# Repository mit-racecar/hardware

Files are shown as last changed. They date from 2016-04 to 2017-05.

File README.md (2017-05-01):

Racecar Hardware
================

This repo has information for recreating the [racecar platform][racecarHomepage]. However, since the racecar platform is still in development, the information in this repo may not always be up to date.

## Bill of Materials (for each car)

### Off the shelf parts
* [Jetson TX1 Developer Kit](http://www.nvidia.com/object/jetson-tx1-dev-kit.html)
* [ZED Stereo Camera](https://www.stereolabs.com/)
* [Hokuyo UST-10LX 2D Lidar](https://acroname.com/products/HOKUYO-UST-10LX-LASER?sku=R359-UST-10LX) 
* [AC1750 Wifi Dual Band Gigabit Router](https://www.amazon.com/TP-Link-Archer-C7-Wireless-Gigabit/dp/B00BUSDVBQ)
* [Ethernet Jumper Cable (1 per car)](https://www.amazon.com/gp/product/B00EEK1114/ref=od_aui_detailpages00?ie=UTF8&psc=1)
* [Traxxas RC Car](https://www.amazon.com/Traxxas-Slash-Brushless-Course-Platinum/dp/B00A0KQH84)
* [7 Port USB 3.0 Hub](https://www.amazon.com/AmazonBasics-Port-USB-Power-Adapter/dp/B00E6GX4BG)
* [Vedder VESC-X HW 4.12 ESC](http://www.enertionboards.com/electric-skateboard-parts/vesc-x-programmable-brushless-motor-controller/)

### Lasercut Parts (from this repo)

* Bottom hardware mounting plate
* Top hardware mounting plate
* Lidar mounting plate
* Extended front bumper

## Notes

### Networking

* The AC1750 Wifi Dual Band Gigabit Routers have a bug in their firmware where "hardware NAT" mode must be disabled for maximum throughput.

[racecarHomepage]: http://racecar.mit.edu/

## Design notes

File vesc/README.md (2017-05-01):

# VESC Configurations

For older VESC versions (i.e. everything except for VESC-X), the 6.141 team recommends using the `6.141_bldc_old_hw_30k_erpm.xml` VESC config.

For the VESC-X, the 6.141 team recommends the `6.141_bldc_VESC_X_hw_30k_erpm.xml` VESC config.

The `traxxas_*` VESC config files are older VESC config versions that were used in previous versions of 6.141.

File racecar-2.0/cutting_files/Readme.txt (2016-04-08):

This set of DXF files contains:

00_RACECAR 12x24 Cutting File.DXF   - Cuts two copies of B1 and B2.

01_RACECAR 12x24 Cutting File.DXF
	thru
06_RACECAR 12x24 Cutting File.DXF   - All of these cut 3 copies of B3.
				      Each one has a different set of
                                      3 car numbers.

All files were made to work with 12x24 sheets of ABS. Note that it is
recommended to construct part B2 out of aluminum instead of ABS to
assist with cooling the laser scanner.

-Owen Guldner

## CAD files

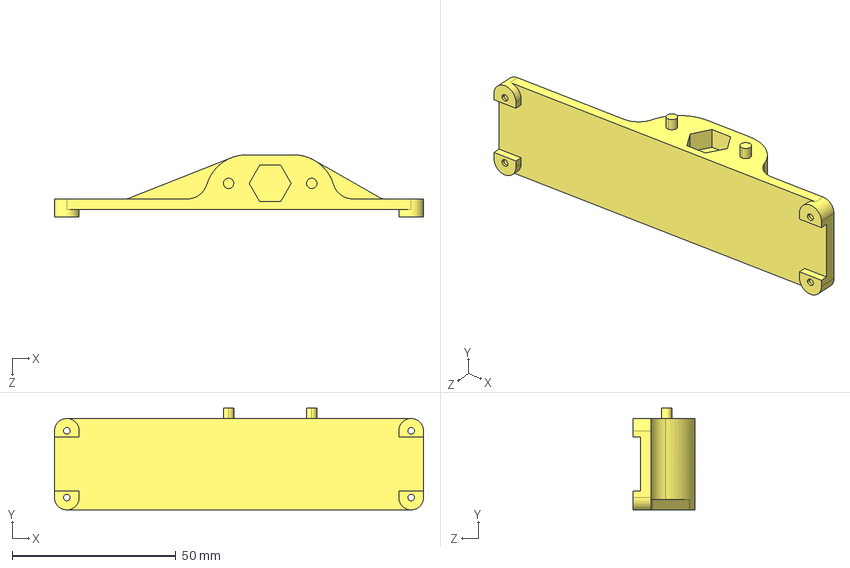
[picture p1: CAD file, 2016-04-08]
racecar-2.0/B5_RevA.STEP
112.7 x 31.1 x 19.1 mm

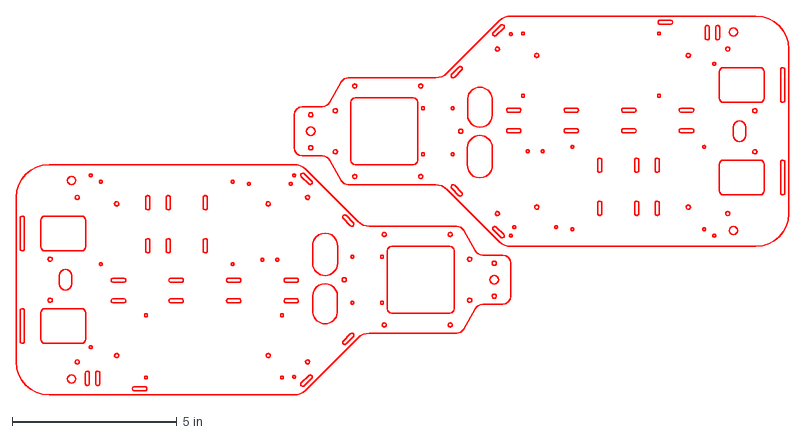
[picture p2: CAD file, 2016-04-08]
racecar-2.0/cutting_files/00_RACECAR 12x24 Cutting File.DXF
23.5 x 11.5 in

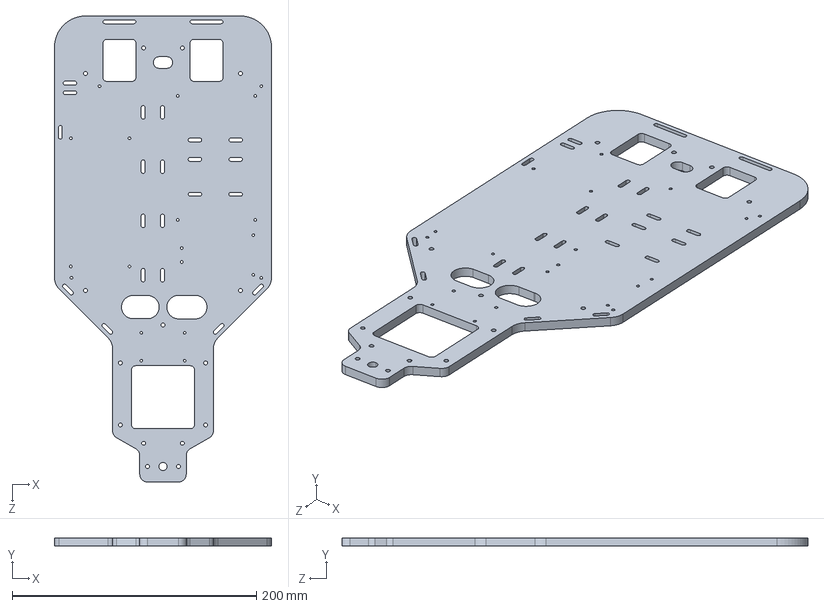
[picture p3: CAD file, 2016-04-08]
racecar-2.0/B1_RevA.STEP
177.8 x 6.35 x 381.8 mm

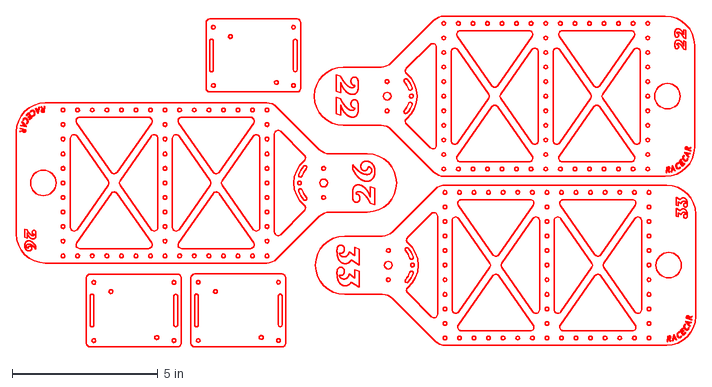
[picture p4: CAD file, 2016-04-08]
racecar-2.0/cutting_files/02_RACECAR 12x24 Cutting File.DXF
23.3 x 11.4 in

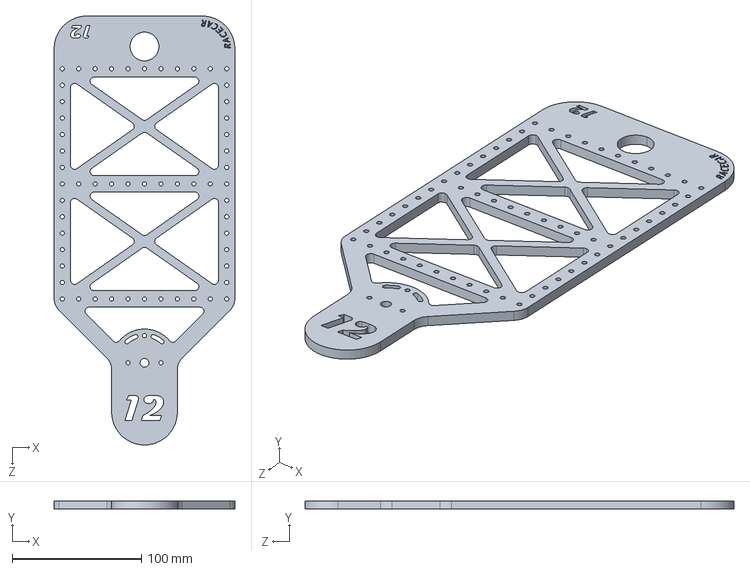
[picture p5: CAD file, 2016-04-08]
racecar-2.0/B3_RevA.STEP
139.7 x 6.35 x 331.4 mm

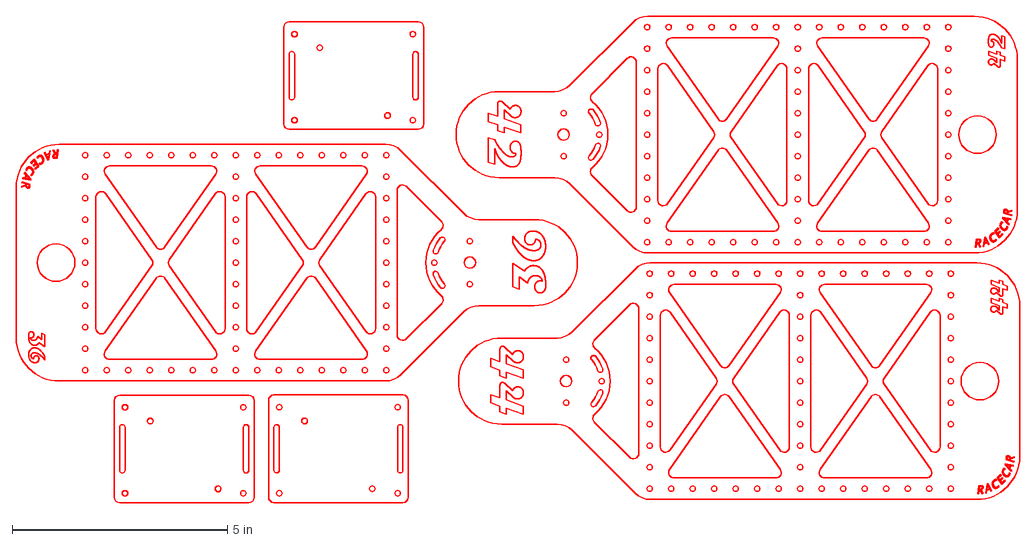
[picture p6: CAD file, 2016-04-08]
racecar-2.0/cutting_files/06_RACECAR 12x24 Cutting File.DXF
23.3 x 11.3 in

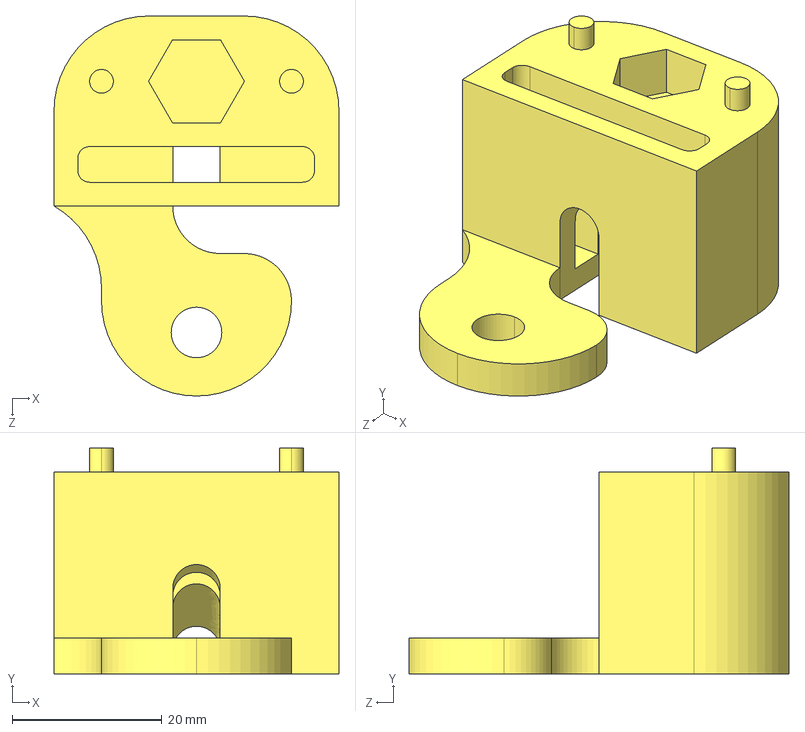
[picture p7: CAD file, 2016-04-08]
racecar-2.0/B4_RevA.STEP
38.1 x 30.2 x 50.8 mm

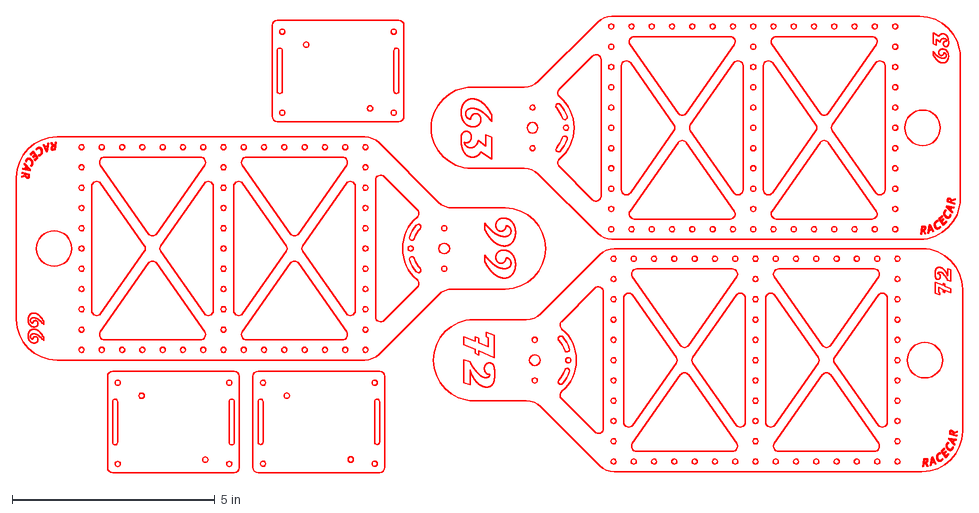
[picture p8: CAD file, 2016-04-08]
racecar-2.0/cutting_files/04_RACECAR 12x24 Cutting File.DXF
23.3 x 11.3 in

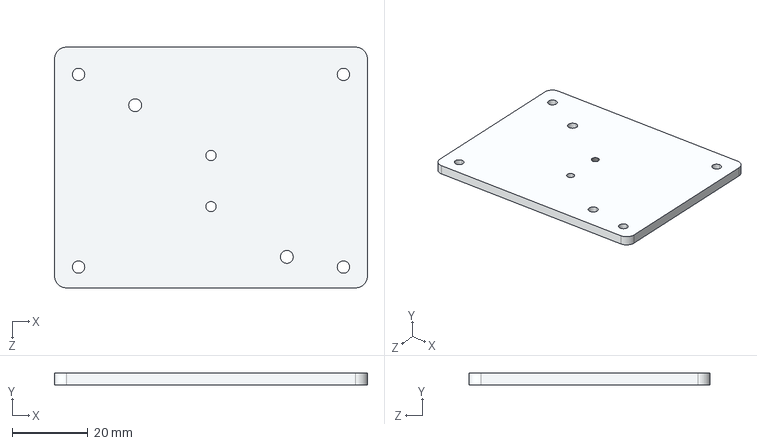
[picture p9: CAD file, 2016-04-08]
racecar-2.0/B2_RevA.STEP
82.5 x 3.18 x 63.5 mm

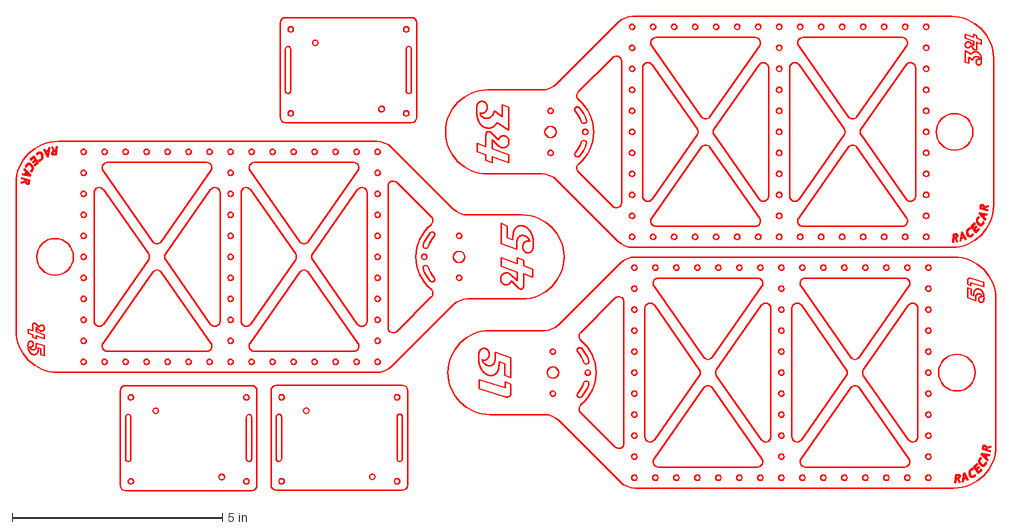
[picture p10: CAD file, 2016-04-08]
racecar-2.0/cutting_files/03_RACECAR 12x24 Cutting File.DXF
23.3 x 11.3 in

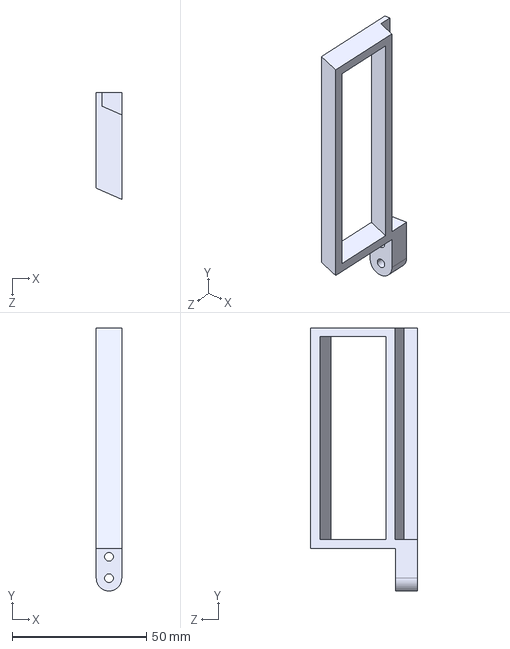
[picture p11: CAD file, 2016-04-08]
racecar-2.0/B6_RevA.STEP
9.53 x 98.0 x 39.8 mm

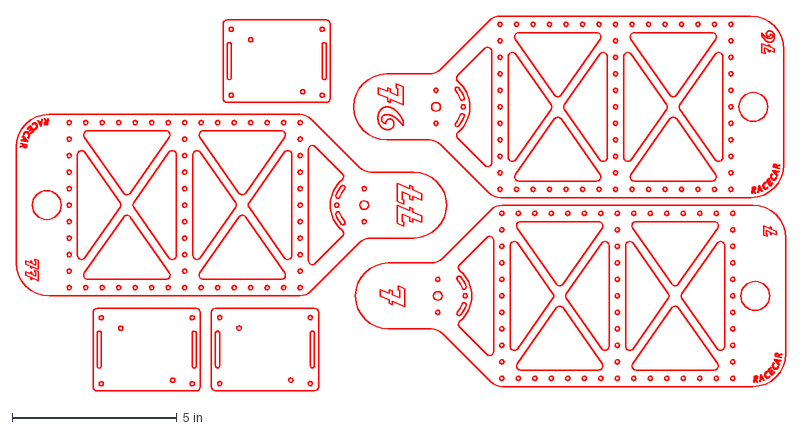
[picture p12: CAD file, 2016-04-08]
racecar-2.0/cutting_files/05_RACECAR 12x24 Cutting File.DXF
23.3 x 11.4 in

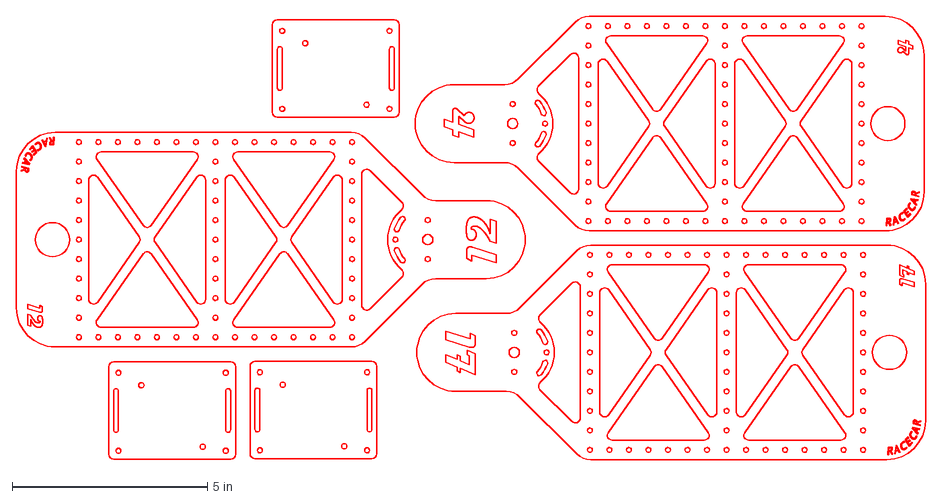
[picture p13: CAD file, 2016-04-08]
racecar-2.0/cutting_files/01_RACECAR 12x24 Cutting File.DXF
23.3 x 11.4 in

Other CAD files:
racecar-2.0/B4_RevA.STL
racecar-2.0/B5_RevA.STL
racecar-2.0/B6_RevA.STL

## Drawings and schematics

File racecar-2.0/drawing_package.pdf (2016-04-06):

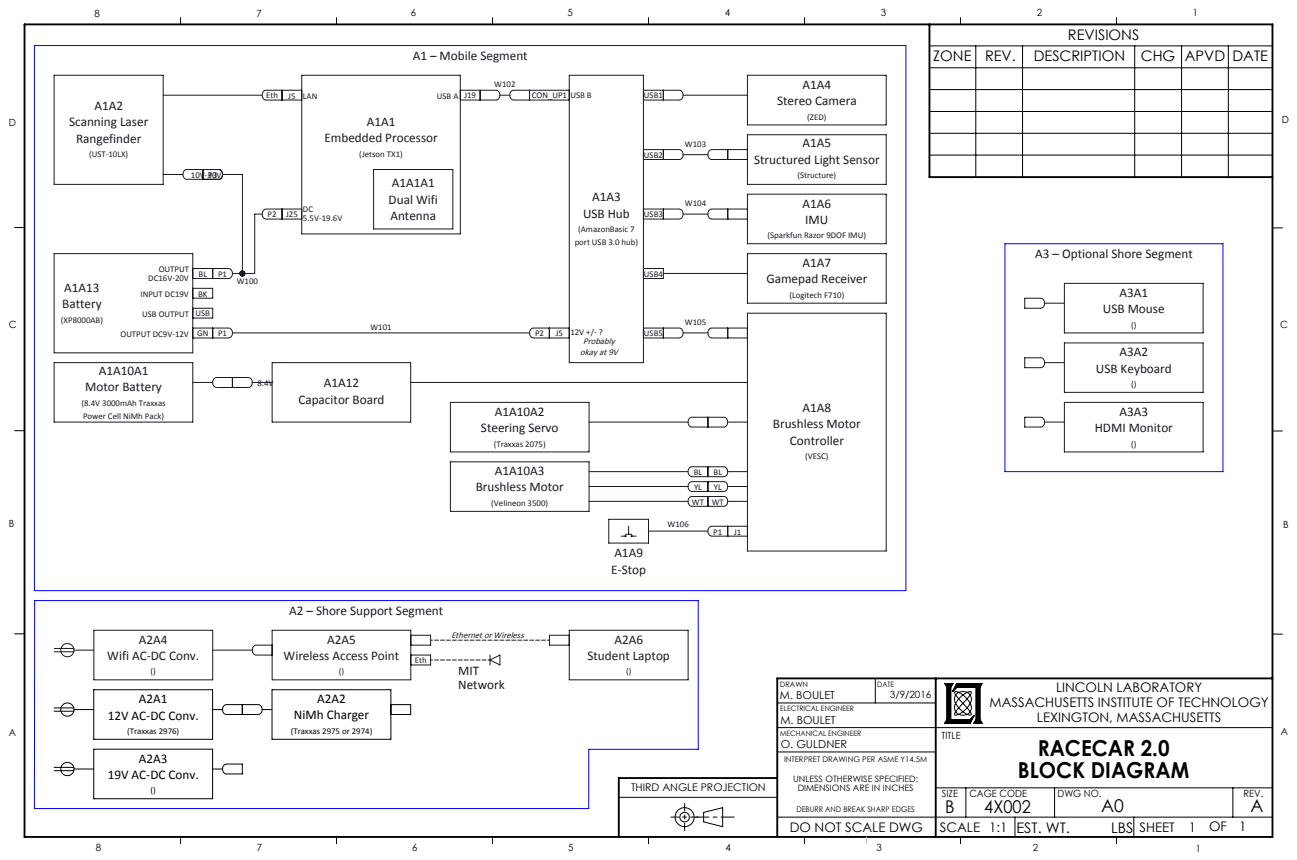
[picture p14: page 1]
Ethernet or Wireless; Student Laptop; NiMh Charger; (Traxxas 2975 or 2974); A1 – Mobile Segment; Embedded Processor; (Jetson TX1); Structured Light Sensor; Scanning Laser; Brushless Motor; Stereo Camera; INPUT DC19V; USB OUTPUT; OUTPUT DC9V-12V; USB A; CON_UP1 USB B; USB1; okay at 9V; Steering Servo; (Traxxas 2075); (Velineon 3500); USB Mouse; USB Keyboard; HDMI Monitor; Capacitor Board; Dual Wifi; RACECAR 2.0 BLOCK DIAGRAM; LINCOLN LABORATORY; LEXINGTON, MASSACHUSETTS

REVISIONS

ZONE | REV. | DESCRIPTION | CHG | APVD | DATE

USB Hub
(AmazonBasic 7
port USB 3.0 hub)

(Sparkfun Razor 9DOF IMU)
Gamepad Receiver
(Logitech F710)

A3 – Optional Shore Segment

Motor Battery
(8.4V 3000mAh Traxxas
Power Cell NiMh Pack)

A2 – Shore Support Segment
Wireless Access Point

Wifi AC-DC Conv.
12V AC-DC Conv.
(Traxxas 2976)
19V AC-DC Conv.

M. BOULET
ELECTRICAL ENGINEER
MECHANICAL ENGINEER
O. GULDNER
INTERPRET DRAWING PER ASME Y14.5M
UNLESS OTHERWISE SPECIFIED:
DIMENSIONS ARE IN INCHES

MASSACHUSETTS INSTITUTE OF TECHNOLOGY

THIRD ANGLE PROJECTION

SIZE B | CAGE CODE 4X002 | DWG NO. A0 | REV. A

DEBURR AND BREAK SHARP EDGES

DO NOT SCALE DWG | SCALE 1:1 | EST. WT. LBS | SHEET 1 OF 1

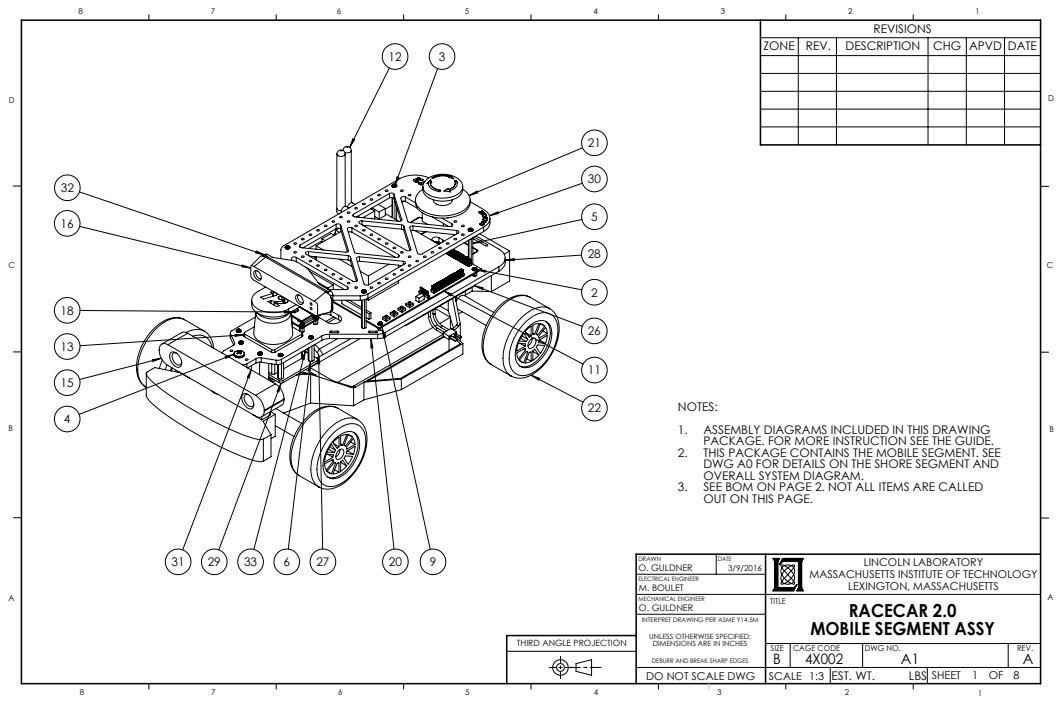
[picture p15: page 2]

NOTES:
1. ASSEMBLY DIAGRAMS INCLUDED IN THIS DRAWING
PACKAGE. FOR MORE INSTRUCTION SEE THE GUIDE.
2. THIS PACKAGE CONTAINS THE MOBILE SEGMENT. SEE
DWG A0 FOR DETAILS ON THE SHORE SEGMENT AND
OVERALL SYSTEM DIAGRAM.
3. SEE BOM ON PAGE 2. NOT ALL ITEMS ARE CALLED
OUT ON THIS PAGE.

LINCOLN LABORATORY
LEXINGTON, MASSACHUSETTS
RACECAR 2.0
MOBILE SEGMENT ASSY

O. GULDNER
ELECTRICAL ENGINEER
M. BOULET
MECHANICAL ENGINEER
INTERPRET DRAWING PER ASME Y14.5M
UNLESS OTHERWISE SPECIFIED:
DIMENSIONS ARE IN INCHES

MASSACHUSETTS INSTITUTE OF TECHNOLOGY

THIRD ANGLE PROJECTION

SIZE | CAGE CODE | DWG NO. A1 | REV. A

DO NOT SCALE DWG | 1:3 | | SHEET 1 OF 8

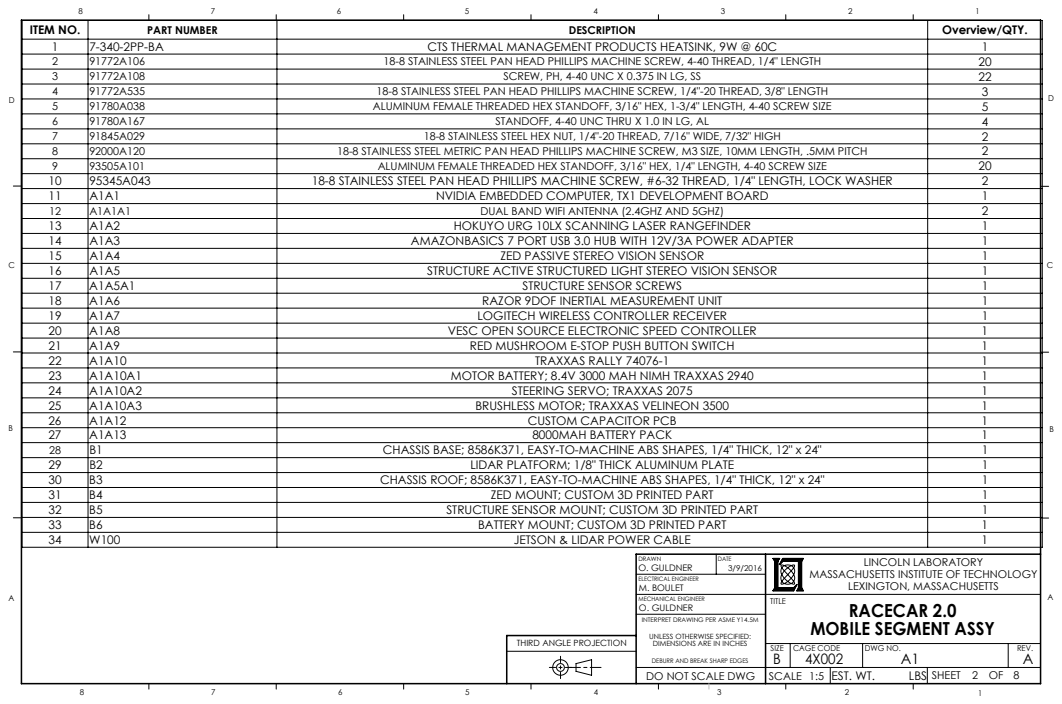
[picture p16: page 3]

ITEM NO. | PART NUMBER | DESCRIPTION | Overview/QTY.
1 | 7-340-2PP-BA | CTS THERMAL MANAGEMENT PRODUCTS HEATSINK, 9W @ 60C | 1
2 | 91772A106 | 18-8 STAINLESS STEEL PAN HEAD PHILLIPS MACHINE SCREW, 4-40 THREAD, 1/4" LENGTH | 20
3 | 91772A108 | SCREW, PH, 4-40 UNC X 0.375 IN LG, SS | 22
4 | 91772A535 | 18-8 STAINLESS STEEL PAN HEAD PHILLIPS MACHINE SCREW, 1/4"-20 THREAD, 3/8" LENGTH | 3
5 | 91780A038 | ALUMINUM FEMALE THREADED HEX STANDOFF, 3/16" HEX, 1-3/4" LENGTH, 4-40 SCREW SIZE | 5
6 | 91780A167 | STANDOFF, 4-40 UNC THRU X 1.0 IN LG, AL | 4
7 | 91845A029 | 18-8 STAINLESS STEEL HEX NUT, 1/4"-20 THREAD, 7/16" WIDE, 7/32" HIGH | 2
8 | 92000A120 | 18-8 STAINLESS STEEL METRIC PAN HEAD PHILLIPS MACHINE SCREW, M3 SIZE, 10MM LENGTH, .5MM PITCH | 2
9 | 93505A101 | ALUMINUM FEMALE THREADED HEX STANDOFF, 3/16" HEX, 1/4" LENGTH, 4-40 SCREW SIZE | 20
10 | 95345A043 | 18-8 STAINLESS STEEL PAN HEAD PHILLIPS MACHINE SCREW, #6-32 THREAD, 1/4" LENGTH, LOCK WASHER | 2
11 | A1A1 | NVIDIA EMBEDDED COMPUTER, TX1 DEVELOPMENT BOARD | 1
12 | A1A1A1 | DUAL BAND WIFI ANTENNA (2.4GHZ AND 5GHZ) | 2
13 | A1A2 | HOKUYO URG 10LX SCANNING LASER RANGEFINDER | 1
14 | A1A3 | AMAZONBASICS 7 PORT USB 3.0 HUB WITH 12V/3A POWER ADAPTER | 1
15 | A1A4 | ZED PASSIVE STEREO VISION SENSOR | 1
16 | A1A5 | STRUCTURE ACTIVE STRUCTURED LIGHT STEREO VISION SENSOR | 1
17 | A1A5A1 | STRUCTURE SENSOR SCREWS | 1
18 | A1A6 | RAZOR 9DOF INERTIAL MEASUREMENT UNIT | 1
19 | A1A7 | LOGITECH WIRELESS CONTROLLER RECEIVER | 1
20 | A1A8 | VESC OPEN SOURCE ELECTRONIC SPEED CONTROLLER | 1
21 | A1A9 | RED MUSHROOM E-STOP PUSH BUTTON SWITCH | 1
22 | A1A10 | TRAXXAS RALLY 74076-1 | 1
23 | A1A10A1 | MOTOR BATTERY; 8.4V 3000 MAH NIMH TRAXXAS 2940 | 1
24 | A1A10A2 | STEERING SERVO; TRAXXAS 2075 | 1
25 | A1A10A3 | BRUSHLESS MOTOR; TRAXXAS VELINEON 3500 | 1
26 | A1A12 | CUSTOM CAPACITOR PCB | 1
27 | A1A13 | 8000MAH BATTERY PACK | 1
28 | B1 | CHASSIS BASE; 8586K371, EASY-TO-MACHINE ABS SHAPES, 1/4" THICK, 12" x 24" | 1
29 | B2 | LIDAR PLATFORM; 1/8" THICK ALUMINUM PLATE | 1
30 | B3 | CHASSIS ROOF; 8586K371, EASY-TO-MACHINE ABS SHAPES, 1/4" THICK, 12" x 24" | 1
31 | B4 | ZED MOUNT; CUSTOM 3D PRINTED PART | 1
32 33 | B5 B6 | STRUCTURE SENSOR MOUNT; CUSTOM 3D PRINTED PART BATTERY MOUNT; CUSTOM 3D PRINTED PART | 1 1
34 | W100 | JETSON & LIDAR POWER CABLE | 1

LINCOLN LABORATORY
LEXINGTON, MASSACHUSETTS
RACECAR 2.0
MOBILE SEGMENT ASSY

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

MASSACHUSETTS INSTITUTE OF TECHNOLOGY
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

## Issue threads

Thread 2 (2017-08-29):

how to center the servo

nes123, 2017-08-29:
any idea how to center the servo ? the car turns left in its natural state

cpchpatrick, 2019-08-07:
Hi, may I ask how do you control the servo?
My servo doesn't respond to any of my commands, it stays at natural state forever.

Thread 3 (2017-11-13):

Question about drawing package

bpinaya, 2017-11-13:
Hi there, I was just wondering what drawing package you used to make the designs. It looks like SolidWorks but I can't be sure, mind telling which one you used?
Kind regards

sourabhrajwade, 2019-01-22:
Hi!
I am looking at the design. I just want to know about the suspension design.

mboulet, 2019-01-27:
@bpinaya Yes, it is Solidworks for the 3D models. Visio was used to create some of the 2D drawings.

@sourabhrajwade We sometimes add stiffer springs to the suspension due to the weight of the processor and sensors. Otherwise it is out-of-the-box Traxxas suspension.

Closed 2019-01-27.

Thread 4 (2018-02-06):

New cutting files

MTDzi, 2018-02-06:
Hi,

a big thank you for the content!

I'm planning to build my own RACECAR, and one source that turned out to be very handy is jetsonhacks.com, and in the following video:
www.jetsonhacks.com/2017/04/03/jetson-racecar-restart/
Jim says that he uses cuts from version 2.5 of the MIT-RACECAR.

I was wondering if you're planning to share this version too, or (perhaps) the differences between 2.0 and 2.5 are sufficiently small so that it shouldn't make much difference.

I would really appreciate an answer (even a short one).
Thanks!

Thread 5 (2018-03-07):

Why I cannot open this files?

tomek242, 2018-03-07:
As I said in Issue topic. I cannot open this files any auto CAD. I was try to open this files by LibreCAD - result nothing was happens.
Someone had this problem?
Greetings

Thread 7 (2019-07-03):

enertion focbox

ArtlyStyles, 2019-07-03:
This device is very hard to find now. Any other VESC can replace this?

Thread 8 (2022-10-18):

Can VESC be used for Spektrum ESC and servo?

jonbakerfish, 2022-10-18:
Hi, I'm planning to build a self-driving RC car with [ARRMA FIRETEAM](https://www.arrma-rc.com/en/product/1-7-fireteam-6s-4wd-blx-speed-assault-vehicle-rtr-black/ARA7618T1.html). I'm not sure whether it's Spektrum ESC and servo are programmable and is VESC capable of doing this? Can you advise on how to do the control part using new hardware?

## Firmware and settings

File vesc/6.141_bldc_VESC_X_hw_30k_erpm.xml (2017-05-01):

<?xml version="1.0" encoding="UTF-8"?>
<MCConfiguration>
    <pwm_mode>1</pwm_mode>
    <comm_mode>0</comm_mode>
    <motor_type>0</motor_type>
    <sensor_mode>0</sensor_mode>
    <l_current_max>60</l_current_max>
    <l_current_min>-60</l_current_min>
    <l_in_current_max>60</l_in_current_max>
    <l_in_current_min>-20</l_in_current_min>
    <l_abs_current_max>130</l_abs_current_max>
    <l_min_erpm>-30000</l_min_erpm>
    <l_max_erpm>30000</l_max_erpm>
    <l_max_erpm_fbrake>30000</l_max_erpm_fbrake>
    <l_max_erpm_fbrake_cc>30000</l_max_erpm_fbrake_cc>
    <l_min_vin>8</l_min_vin>
    <l_max_vin>57</l_max_vin>
    <l_battery_cut_start>10</l_battery_cut_start>
    <l_battery_cut_end>8</l_battery_cut_end>
    <l_slow_abs_current>1</l_slow_abs_current>
    <l_rpm_lim_neg_torque>1</l_rpm_lim_neg_torque>
    <l_temp_fet_start>80</l_temp_fet_start>
    <l_temp_fet_end>100</l_temp_fet_end>
    <l_temp_motor_start>80</l_temp_motor_start>
    <l_temp_motor_end>100</l_temp_motor_end>
    <l_min_duty>0.005</l_min_duty>
    <l_max_duty>0.95</l_max_duty>
    <sl_min_erpm>150</sl_min_erpm>
    <sl_min_erpm_cycle_int_limit>1700</sl_min_erpm_cycle_int_limit>
    <sl_max_fullbreak_current_dir_change>10</sl_max_fullbreak_current_dir_change>
    <sl_cycle_int_limit>62</sl_cycle_int_limit>
    <sl_cycle_int_limit_high_fac>0.8</sl_cycle_int_limit_high_fac>
    <sl_cycle_int_rpm_br>80000</sl_cycle_int_rpm_br>
    <sl_bemf_coupling_k>600</sl_bemf_coupling_k>
    <hall_table_0>-1</hall_table_0>
    <hall_table_1>1</hall_table_1>
    <hall_table_2>3</hall_table_2>
    <hall_table_3>2</hall_table_3>
    <hall_table_4>5</hall_table_4>
    <hall_table_5>6</hall_table_5>
    <hall_table_6>4</hall_table_6>
    <hall_table_7>-1</hall_table_7>
    <hall_sl_erpm>2000</hall_sl_erpm>
    <foc_current_kp>0.03</foc_current_kp>
    <foc_current_ki>50</foc_current_ki>
    <foc_f_sw>20000</foc_f_sw>
    <foc_dt_us>0.08</foc_dt_us>
    <foc_encoder_inverted>0</foc_encoder_inverted>
    <foc_encoder_offset>180</foc_encoder_offset>
    <foc_encoder_ratio>7</foc_encoder_ratio>
    <foc_sensor_mode>0</foc_sensor_mode>
    <foc_pll_kp>2000</foc_pll_kp>
    <foc_pll_ki>20000</foc_pll_ki>
    <foc_motor_l>7e-06</foc_motor_l>
    <foc_motor_r>0.015</foc_motor_r>
    <foc_motor_flux_linkage>0.00245</foc_motor_flux_linkage>
    <foc_observer_gain>9e+07</foc_observer_gain>
    <foc_duty_dowmramp_kp>10</foc_duty_dowmramp_kp>
    <foc_duty_dowmramp_ki>200</foc_duty_dowmramp_ki>
    <foc_openloop_rpm>1200</foc_openloop_rpm>
    <foc_sl_openloop_hyst>0.5</foc_sl_openloop_hyst>
    <foc_sl_openloop_time>0.5</foc_sl_openloop_time>
    <foc_sl_d_current_duty>0</foc_sl_d_current_duty>
    <foc_sl_d_current_factor>0</foc_sl_d_current_factor>
    <foc_hall_table_0>255</foc_hall_table_0>
    <foc_hall_table_1>255</foc_hall_table_1>
    <foc_hall_table_2>255</foc_hall_table_2>
    <foc_hall_table_3>255</foc_hall_table_3>
    <foc_hall_table_4>255</foc_hall_table_4>
    <foc_hall_table_5>255</foc_hall_table_5>
    <foc_hall_table_6>255</foc_hall_table_6>
    <foc_hall_table_7>255</foc_hall_table_7>
    <foc_sl_erpm>2500</foc_sl_erpm>
    <s_pid_kp>0.0001</s_pid_kp>
    <s_pid_ki>0.015</s_pid_ki>
    <s_pid_kd>0</s_pid_kd>
    <s_pid_min_rpm>900</s_pid_min_rpm>
    <p_pid_kp>0.03</p_pid_kp>
    <p_pid_ki>0</p_pid_ki>
    <p_pid_kd>0.0004</p_pid_kd>
    <p_pid_ang_div>1</p_pid_ang_div>
    <cc_startup_boost_duty>0.01</cc_startup_boost_duty>
    <cc_min_current>1</cc_min_current>
    <cc_gain>0.0046</cc_gain>
    <cc_ramp_step_max>0.4</cc_ramp_step_max>
    <m_fault_stop_time_ms>3000</m_fault_stop_time_ms>
    <m_duty_ramp_step>0.02</m_duty_ramp_step>
    <m_duty_ramp_step_rpm_lim>0.0005</m_duty_ramp_step_rpm_lim>
    <m_current_backoff_gain>0.5</m_current_backoff_gain>
    <m_encoder_counts>8192</m_encoder_counts>
    <m_sensor_port_mode>0</m_sensor_port_mode>
    <meta_description>&lt;!DOCTYPE HTML PUBLIC &quot;-//W3C//DTD HTML 4.0//EN&quot; &quot;http://www.w3.org/TR/REC-html40/strict.dtd&quot;&gt;
&lt;html&gt;&lt;head&gt;&lt;meta name=&quot;qrichtext&quot; content=&quot;1&quot; /&gt;&lt;style type=&quot;text/css&quot;&gt;
p, li { white-space: pre-wrap; }
&lt;/style&gt;&lt;/head&gt;&lt;body style=&quot; font-family:'Ubuntu'; font-size:11pt; font-weight:400; font-style:normal;&quot;&gt;
&lt;p style=&quot; margin-top:0px; margin-bottom:0px; margin-left:0px; margin-right:0px; -qt-block-indent:0; text-indent:0px;&quot;&gt;Configuration loaded from the motor controller.&lt;/p&gt;&lt;/body&gt;&lt;/html&gt;</meta_description>
</MCConfiguration>

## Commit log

2016-01-18 adding racecar vesc config file
    [racecar_vesc_config.xml]
2016-04-08 add model and cutting files
    [00_RACECAR 12x24 Cutting File.DXF, 01_RACECAR 12x24 Cutting File.DXF, 02_RACECAR 12x24 Cutting File.DXF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]
2016-09-12 add new vesc config for traxxas motor, duty cycle good at 0.03, velocity mode is NOT stable
2017-05-01 Added current VESC configs used by 6.141
    [6.141_bldc_VESC_X_hw_30k_erpm.xml]
